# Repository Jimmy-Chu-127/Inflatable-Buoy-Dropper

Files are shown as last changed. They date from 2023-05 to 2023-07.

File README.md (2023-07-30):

# Inflatable Buoy Dropper

### Webpage
https://sites.google.com/ucsd.edu/littlefrog/home?authuser=1

### Demo Video
[](https://youtu.be/II8ibG0zH5Y
"Inflatable Buoy Dropper")

### Objective:
This device is intended to be a drone attachment that can be dropped to drowning victim and inflate upon detecting water.

### Functional Description:
1. Long range dropping control through ESP32 Lora
2. Water sensor to automatically initiate inflation upon hitting water

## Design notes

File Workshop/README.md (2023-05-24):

# Servos and Stepper Motor controls using Arduino
## INDEX
1. Overview
2. PART1: Servos
3. Servos: An introduction
4. Servos: Use cases
5. Servos: Coding and controls
6. Servos: Cool Experiment
8. PART2: Stepper Motors
9. Stepper Motors: An introduction
10. Stepper Motors: Use cases
11. Stepper Motors: Coding and controls
12. Stepper Motors: Cool Experiment

## Servos: An introduction

At its core, a servo motor is a type of motor that can rotate or push parts of a machine with high precision. The key characteristics that set servo motors apart from other types of motors are their control, precision, and feedback.

The unique aspect of servo motors is their use of a "closed-loop" control system. In simple terms, a closed-loop system means that the motor continually receives and responds to feedback about its position or speed, allowing it to make precise adjustments as necessary.

This feedback mechanism typically involves a potentiometer or an encoder that is connected to the motor's output shaft. This device can detect the shaft's current position or speed and send this information back to the motor's control circuit. 

The control circuit then compares the actual position or speed of the shaft with the desired position or speed (as specified by the input signal). If there's a difference, the control circuit will adjust the power to the motor to correct it.

__Factoid__:
The word "servo" comes from the Latin "servus", meaning slave. A servo motor is effectively a slave to its input signals, adjusting its speed, position, or torque based on the instructions it receives.

 Reference: https://howtomechatronics.com/how-it-works/how-servo-motors-work-how-to-control-servos-using-arduino/

### Types of Servos:
 Certainly! There are several types of servo motors, each with unique characteristics and suited to specific applications. Here are some of the most common types:

**1. Standard Servos:** These are the most common types of servo motors. They have a limited rotation angle, typically around 180 degrees. You'll find these in many hobbyist applications like model airplanes or simple robotic arms. These servos have a physical stop built into the gear mechanism to prevent turning beyond these limits.

**2. Continuous Rotation Servos:** Unlike standard servos, continuous rotation servos can rotate 360 degrees continuously in either direction. They are often used for driving wheels on robots because they can turn all the way around. Rather than controlling position, as with standard servos, a command to a continuous rotation servo is interpreted as a speed and direction.

**3. Winch Servos:** These are similar to standard servos, but they have an extended rotation range, typically around 270 degrees. These servos are often used in applications where a larger range of motion is required, such as steering a remote-controlled boat or car.

**4. Linear Servos:** Instead of a rotary actuator, these servos have a linear actuator. This means they move in a straight line rather than rotating. These types of servos are often used in applications where linear motion is required, such as moving a control surface in a straight line.

**5. Large Scale or Giant Servos:** These are high power servos designed for large scale models and other high-stress applications. They provide the same functionality as a standard servo but can deliver much higher torque.

Remember, different servo types require different control signals and power requirements, so always ensure the servo you choose is compatible with your Arduino and the rest of your hardware.

## Servos: Use cases

Servo motors controlled by Arduino find a wide range of applications in various domains due to their precision and control. Here are some key use cases:

**1. Robotics:** In the field of robotics, servos are extensively used. They can be found in robotic arms, legs, or heads to control precise movements. An Arduino can be used to control these servos, allowing you to program complex movements and actions.

**2. Drones and RC Vehicles:** Servo motors are often used in drones and remote-controlled vehicles for steering control, adjusting flight surfaces, or controlling camera gimbal systems. An Arduino can provide the necessary control signals to these servos, making it an ideal choice for hobbyists and professionals alike.

**3. Automation Systems:** In automated systems like home automation or industrial automation, servo motors can be used for a variety of tasks, such as opening or closing valves, adjusting light fixtures, or moving parts in a production line. An Arduino can control these actions based on various sensor inputs.

**4. Interactive Art Installations:** Servo motors controlled by Arduino have become popular in the world of interactive art. They can be used to create moving sculptures, interactive displays, or sound installations, where the motion of the servo motors is controlled by audience interaction.

**5. Animatronics:** In the world of film and entertainment, servos are extensively used in animatronics to create lifelike movements. Arduino can be used to control these servos, making it easier to program and synchronize complex movements.

These examples illustrate just a few of the many possibilities for servo motors controlled by Arduino. With creativity and programming, the applications are virtually endless.

## Servos: Coding and controls

###We focus on regular 180 degree servos first:

The operation of a servo motor is managed by transmitting a sequence of pulses via the signal wire. The control signal should ideally have a frequency of 50Hz, meaning a pulse should be emitted every 20 milliseconds. The angular positioning of the servo is determined by the duration of the pulse. Typically, these servos have the capacity to rotate up to 180 degrees due to their physical constraints on movement.

###Continuous rotation servos:

Continuous rotation servo motors are regulated by a sequence of pulses sent through the signal line. The frequency of the control signal should maintain at 50Hz, which equates to a pulse being produced every 20 milliseconds. Unlike standard servos, the pulse width for a continuous rotation servo does not specify a position, but instead dictates the speed and direction of rotation. These servos, contrary to standard ones, have the ability to rotate without any physical limitations, thereby achieving full 360-degree rotation in either direction.

Arduino code and connections:

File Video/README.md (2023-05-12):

# VIDEO OUTLINE/ IDEAS

## Software:
Davinci Resolve 18

## Ideas
 1. An advert
 2. A video about the problem, solution, roadblock and then the test
    * We should take videos throughout the design process - start early

__IMP:__ 
1. Need to have demo/ deliverable inside of video
2. Need to have voiceovers
3. Find non-copyright music
   
### To Do: 
* Prepare Camera etc for filming in makerspace/ while we are working
* Settle on the format of video - what direction we want
* Decide who is going to edit the video

### Video Outline:
1. Intro - Team name, members - animate this
2. Project Demo - with voiceover - like an advert 
   * Shot of ocean with someone struggling to swim
   * Drone takes off with out attachment
   * Person floats on buoy
4. Cuts of us working on the parts - mashed together - emphasize on one or two bits
5. Outro - with music, credits and links to our project

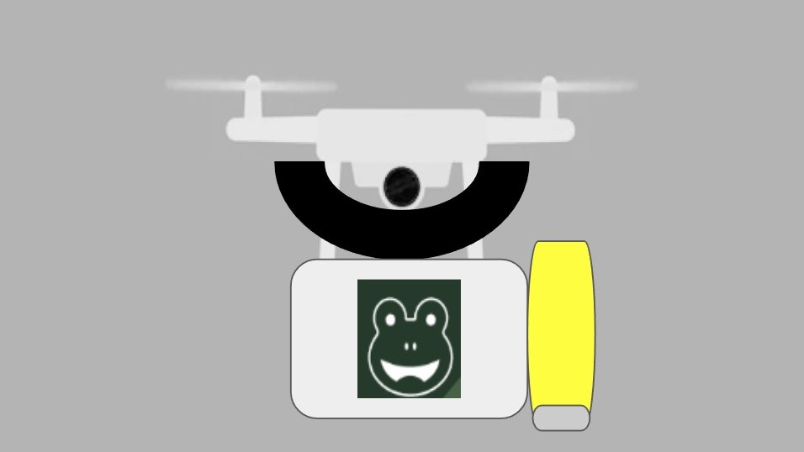
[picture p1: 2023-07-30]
images/Inflatable Buoy Dropper thumbnail.jpg

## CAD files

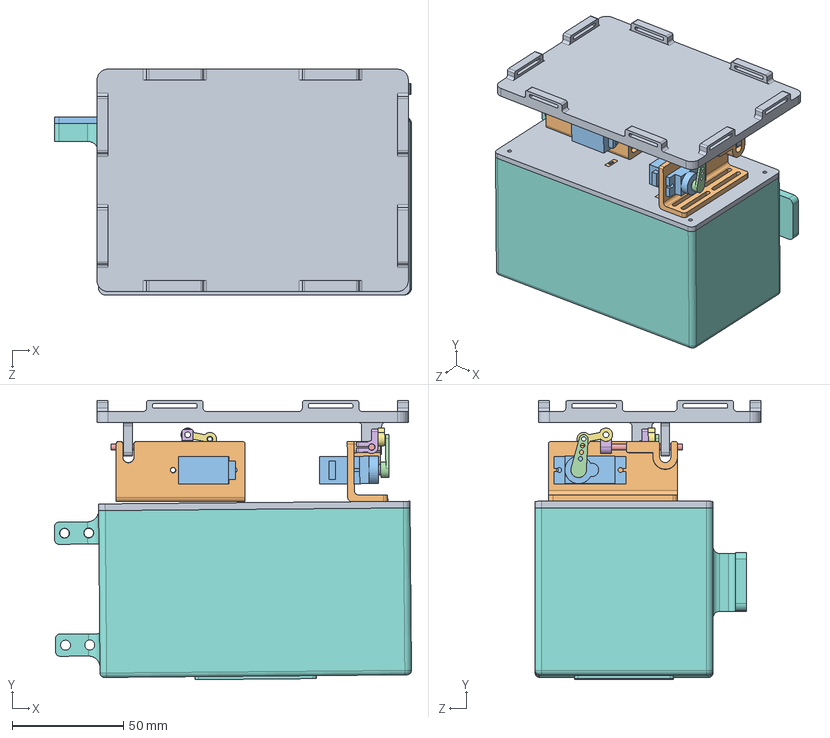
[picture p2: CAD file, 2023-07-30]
Assembly & Parts/Whole mechanism assem.SLDASM
160.4 x 125.5 x 101.5 mm
drone attachment top board
servo attachment x 2
servo x 2
servo arm x 2
servo rod x 2
servo connector 2 x 2
servo connector 3 x 2
PCB Enclosure V3
PCB Enclosure V3 cap
PCB Enclosure water insert x 4

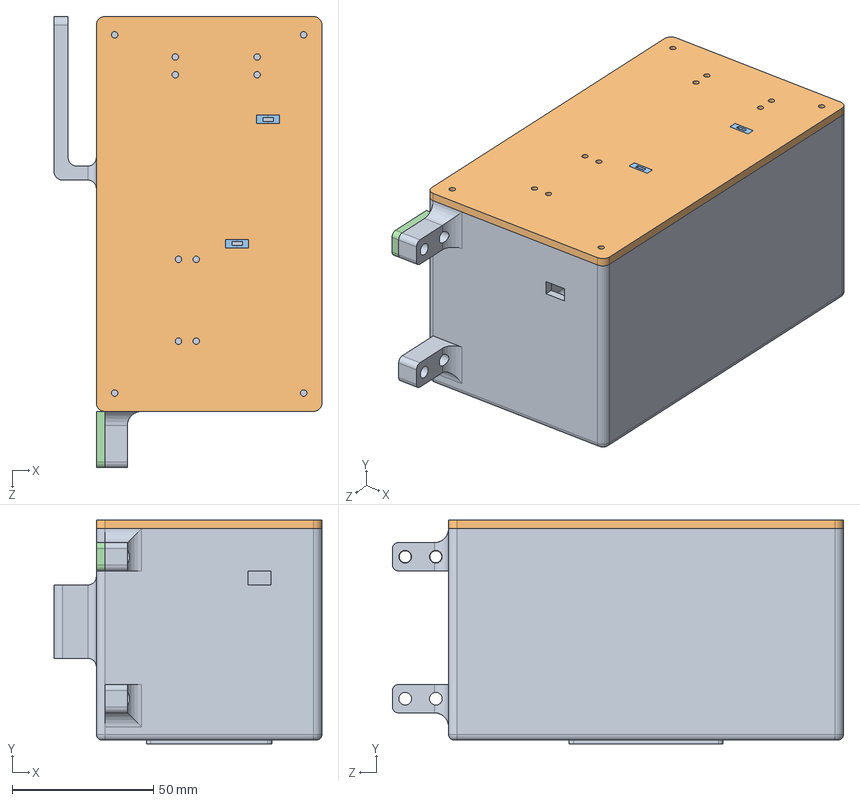
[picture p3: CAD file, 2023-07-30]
Assembly & Parts/PCB Enclosure Assem.SLDASM
95.0 x 79.3 x 159.9 mm
PCB Enclosure V3
PCB Enclosure V3 cap
PCB Enclosure water insert x 4

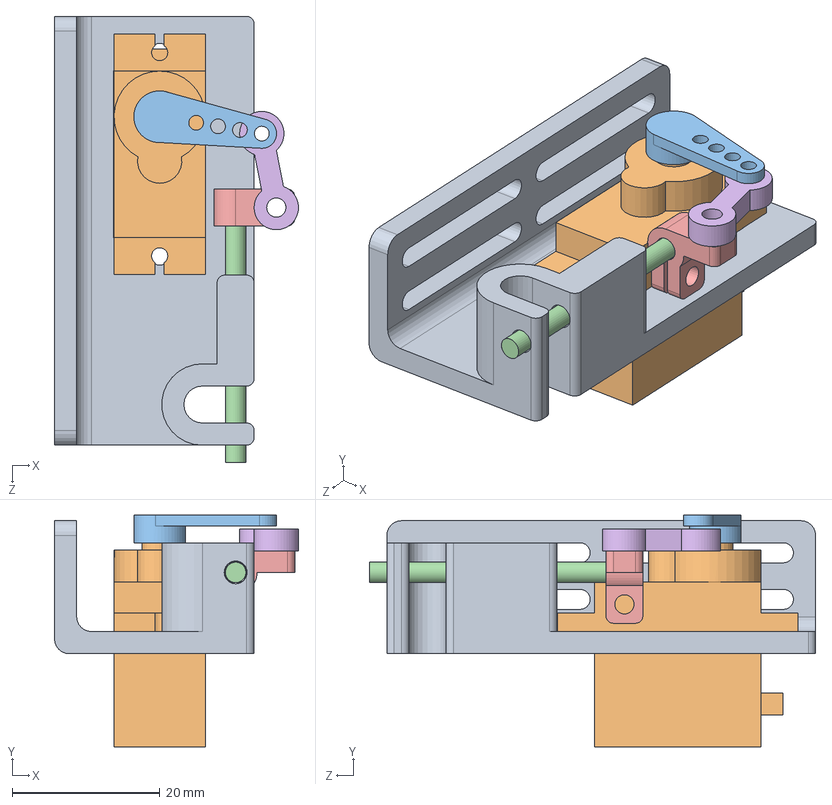
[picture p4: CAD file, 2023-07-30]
Assembly & Parts/servo drop mechanism.SLDASM
33.0 x 31.4 x 60.4 mm
servo attachment
servo
servo arm
servo rod
servo connector 2
servo connector 3

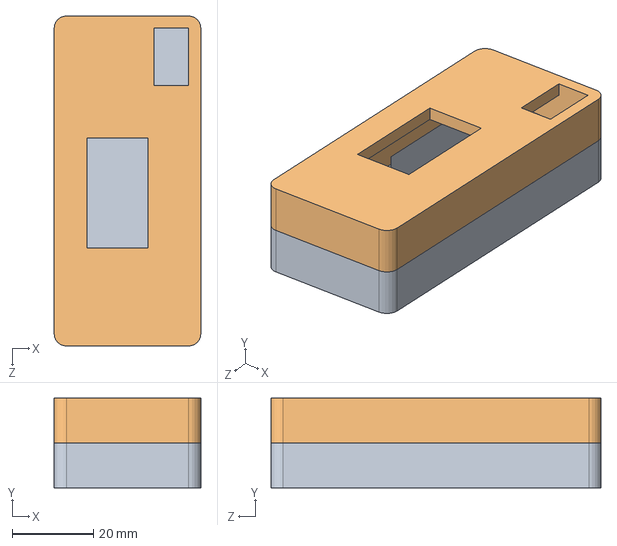
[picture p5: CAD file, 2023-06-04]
Assembly & Parts/Controller Assem.SLDASM
36.0 x 22.0 x 81.0 mm
Controller Enclosure bottom
Controller Enclosure top

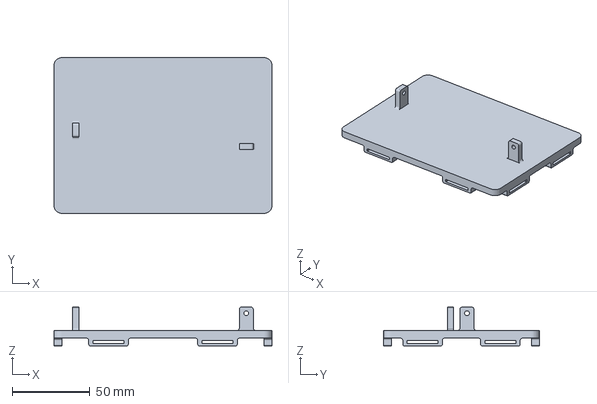
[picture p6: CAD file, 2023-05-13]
3D printing STL files/5.12/drone attachment top board.3mf
140.0 x 100.0 x 25.0 mm

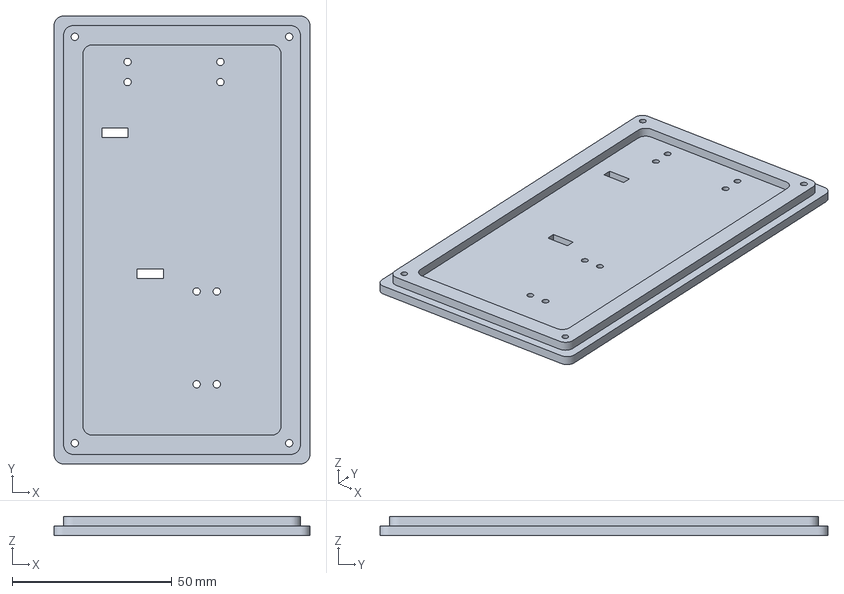
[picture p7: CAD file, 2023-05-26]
3D printing STL files/5.24/3mf/PCB Enclosure V3 cap.3mf
80.0 x 140.0 x 6.00 mm

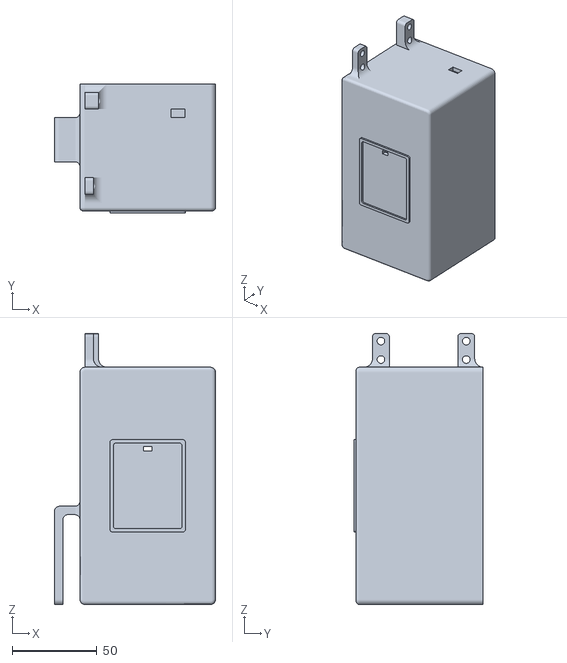
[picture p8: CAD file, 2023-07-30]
3D printing STL files/PCB Enclosure V3.STL
95.0 x 76.4 x 159.9

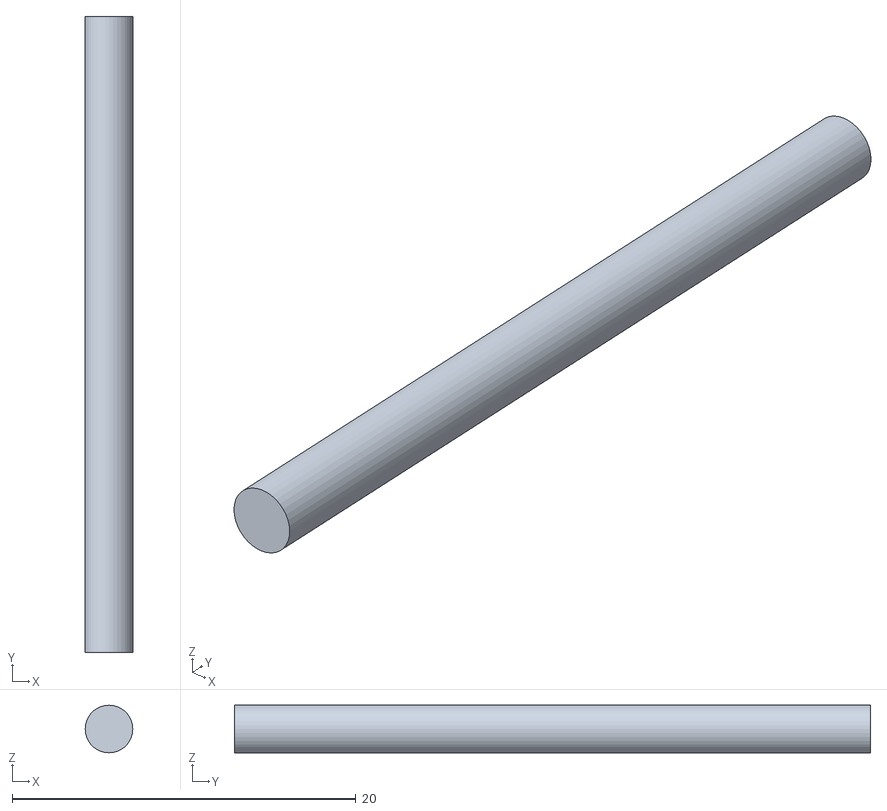
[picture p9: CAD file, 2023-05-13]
3D printing STL files/5.12/servo rod.STL
2.77 x 37.0 x 2.77

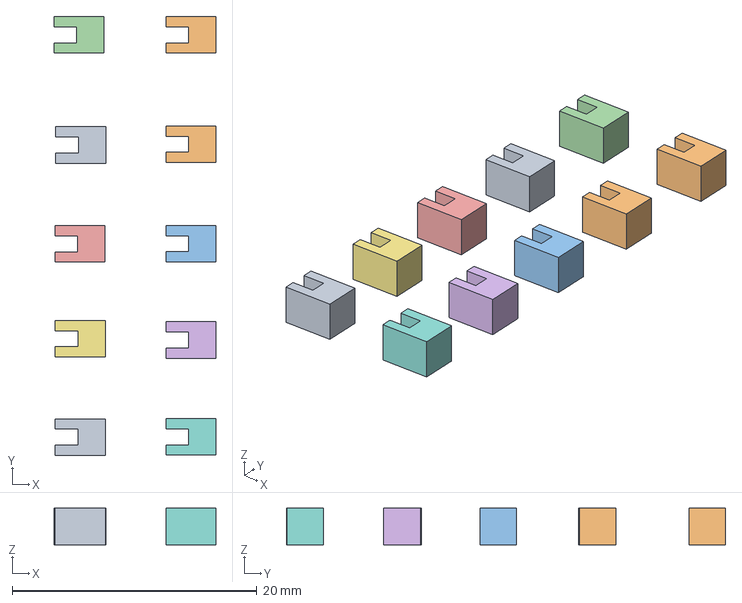
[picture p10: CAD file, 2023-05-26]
3D printing STL files/5.24/3mf/PCB Enclosure water insert.3mf
13.2 x 35.9 x 3.00 mm
PCB Enclosure water insert.STL x 10

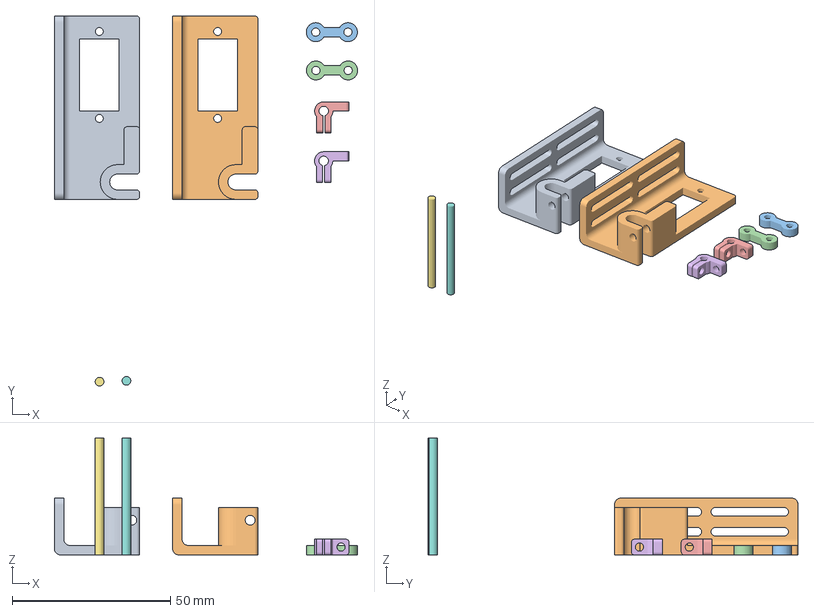
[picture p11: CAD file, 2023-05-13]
3D printing STL files/5.12/servo attachment etc.3mf
95.9 x 117.0 x 37.0 mm
servo attachment.STL x 2
servo connector 3.STL x 2
servo connector 2.STL x 2
servo rod.STL x 2

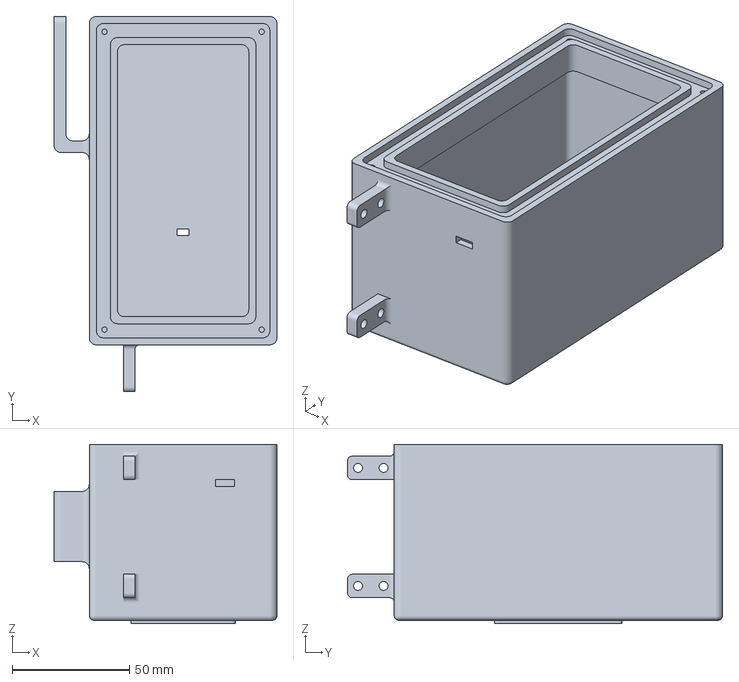
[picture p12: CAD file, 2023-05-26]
3D printing STL files/5.24/3mf/PCB Enclosure V3.3mf
95.0 x 159.9 x 76.4 mm

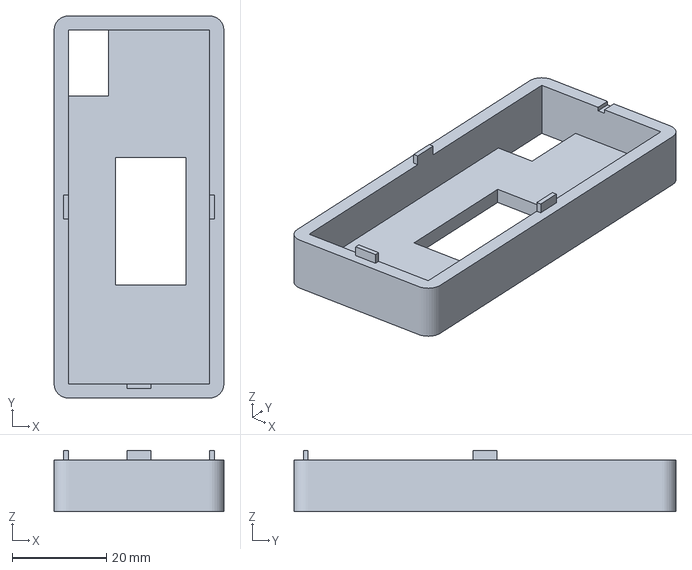
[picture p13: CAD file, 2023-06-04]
3D printing STL files/Controller Enclosure top.3mf
36.0 x 81.0 x 13.0 mm

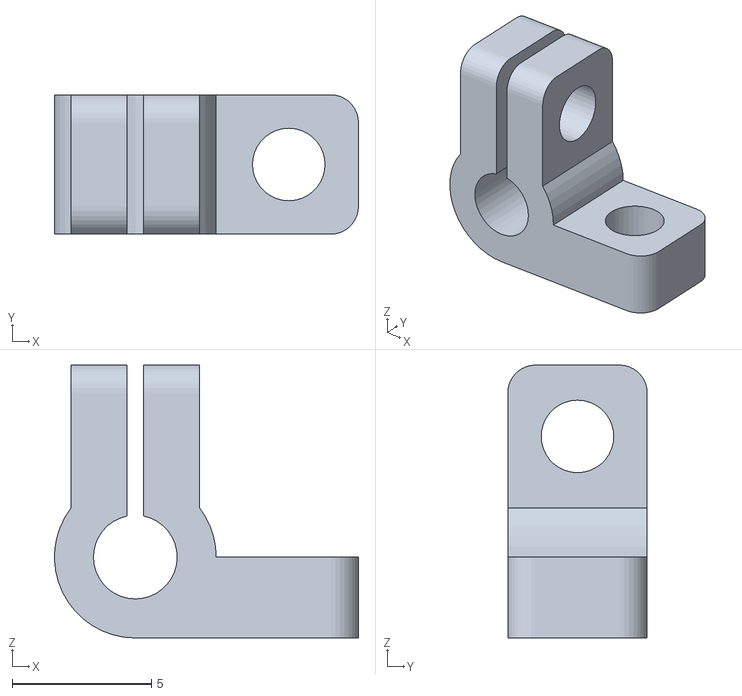
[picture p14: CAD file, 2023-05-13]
3D printing STL files/5.12/servo connector 2.STL
10.9 x 5.00 x 9.78

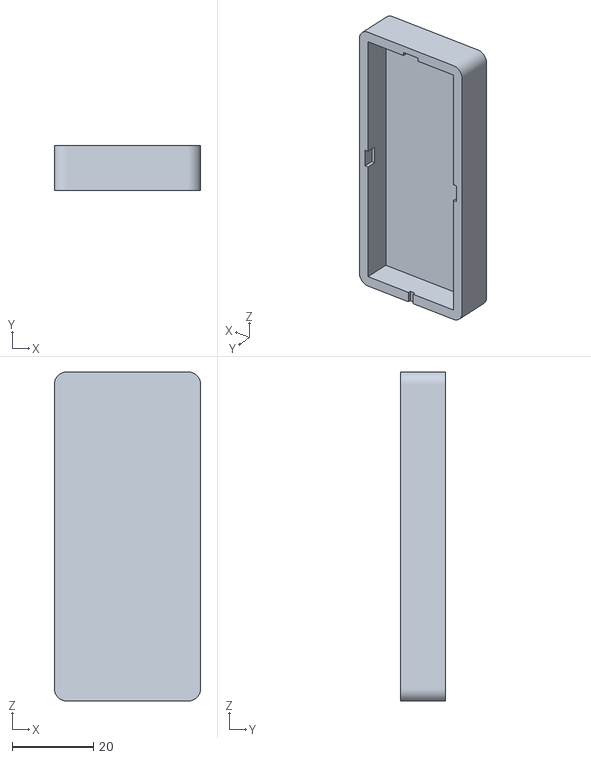
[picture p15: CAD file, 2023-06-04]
3D printing STL files/Controller Enclosure bottom.STL
36.0 x 11.0 x 81.0

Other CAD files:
Assembly & Parts/PCB Enclosure V3 cap.SLDPRT
3D printing STL files/PCB Enclosure V4.3mf
Assembly & Parts/PCB Enclosure V3.SLDPRT
3D printing STL files/5.12/servo connector 3.STL
3D printing STL files/5.12/drone attachment top board.STL
3D printing STL files/5.12/servo attachment.STL
3D printing STL files/5.24/STL/PCB Enclosure V3 cap.STL
3D printing STL files/5.24/STL/PCB Enclosure V3.STL
3D printing STL files/5.24/STL/PCB Enclosure water insert.STL
3D printing STL files/Controller Enclosure top.STL
3D printing STL files/servo height pad.STL
Assembly & Parts/Controller Enclosure bottom.SLDPRT
Assembly & Parts/Controller Enclosure top.SLDPRT
Assembly & Parts/PCB Enclosure V2.SLDPRT
Assembly & Parts/PCB Enclosure water insert.SLDPRT
Assembly & Parts/PCB Enclosure.sldprt
Assembly & Parts/bottom attachment board.SLDPRT
Assembly & Parts/buoy holder.SLDPRT
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

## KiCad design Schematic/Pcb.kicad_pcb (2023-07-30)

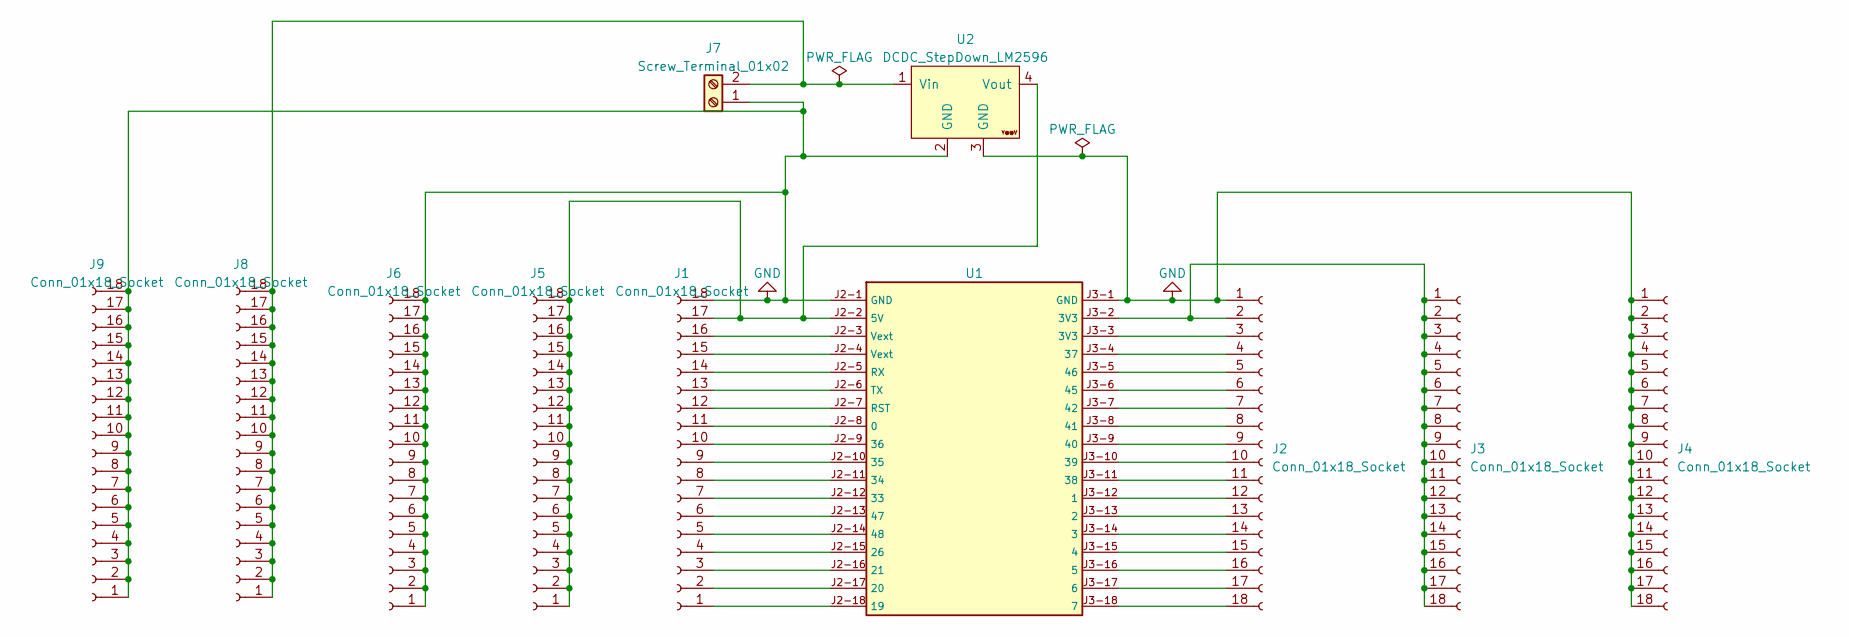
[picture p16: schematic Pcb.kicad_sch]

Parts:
J1, J2, J3, J4, J5, J6, J8, J9: Conn_01x18_Socket; PinSocket_1x18_P2.54mm_Vertical
J7: Screw_Terminal_01x02; TerminalBlock_Altech_AK300-2_P5.00mm
U1: esp32Lora_foot_Print
U2: DCDC_StepDown_LM2596

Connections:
GND: J1.18, J2.1, J4.1, J4.2, J4.3, J4.4, J4.5, J4.6, J4.7, J4.8, J4.9, J4.10, J4.11, J4.12, J4.13, J4.14, J4.15, J4.16, J4.17, J4.18, J6.1, J6.2, J6.3, J6.4, J6.5, J6.6, J6.7, J6.8, J6.9, J6.10, J6.11, J6.12, J6.13, J6.14, J6.15, J6.16, J6.17, J6.18, J7.1, J9.1, J9.2, J9.3, J9.4, J9.5, J9.6, J9.7, J9.8, J9.9, J9.10, J9.11, J9.12, J9.13, J9.14, J9.15, J9.16, J9.17, J9.18, U1.J2-1 (GND), U1.J3-1 (GND), U2.2 (GND), U2.3 (GND)
unnamed: J1.1, U1.J2-18 (19)
unnamed: J1.2, U1.J2-17 (20)
unnamed: J1.3, U1.J2-16 (21)
unnamed: J1.4, U1.J2-15 (26)
unnamed: J1.5, U1.J2-14 (48)
unnamed: J1.6, U1.J2-13 (47)
unnamed: J1.7, U1.J2-12 (33)
unnamed: J1.8, U1.J2-11 (34)
unnamed: J1.9, U1.J2-10 (35)
unnamed: J1.10, U1.J2-9 (36)
unnamed: J1.11, U1.J2-8 (0)
unnamed: J1.12, U1.J2-7 (RST)
unnamed: J1.13, U1.J2-6 (TX)
unnamed: J1.14, U1.J2-5 (RX)
unnamed: J1.15, U1.J2-4 (Vext)
unnamed: J1.16, U1.J2-3 (Vext)
unnamed: J1.17, J5.1, J5.2, J5.3, J5.4, J5.5, J5.6, J5.7, J5.8, J5.9, J5.10, J5.11, J5.12, J5.13, J5.14, J5.15, J5.16, J5.17, J5.18, U1.J2-2 (5V), U2.4 (Vout)
unnamed: J2.2, J3.1, J3.2, J3.3, J3.4, J3.5, J3.6, J3.7, J3.8, J3.9, J3.10, J3.11, J3.12, J3.13, J3.14, J3.15, J3.16, J3.17, J3.18, U1.J3-2 (3V3)
unnamed: J2.3, U1.J3-3 (3V3)
unnamed: J2.4, U1.J3-4 (37)
unnamed: J2.5, U1.J3-5 (46)
unnamed: J2.6, U1.J3-6 (45)
unnamed: J2.7, U1.J3-7 (42)
unnamed: J2.8, U1.J3-8 (41)
unnamed: J2.9, U1.J3-9 (40)
unnamed: J2.10, U1.J3-10 (39)
unnamed: J2.11, U1.J3-11 (38)
unnamed: J2.12, U1.J3-12 (1)
unnamed: J2.13, U1.J3-13 (2)
unnamed: J2.14, U1.J3-14 (3)
unnamed: J2.15, U1.J3-15 (4)
unnamed: J2.16, U1.J3-16 (5)
unnamed: J2.17, U1.J3-17 (6)
unnamed: J2.18, U1.J3-18 (7)
unnamed: J7.2, J8.1, J8.2, J8.3, J8.4, J8.5, J8.6, J8.7, J8.8, J8.9, J8.10, J8.11, J8.12, J8.13, J8.14, J8.15, J8.16, J8.17, J8.18, U2.1 (Vin)

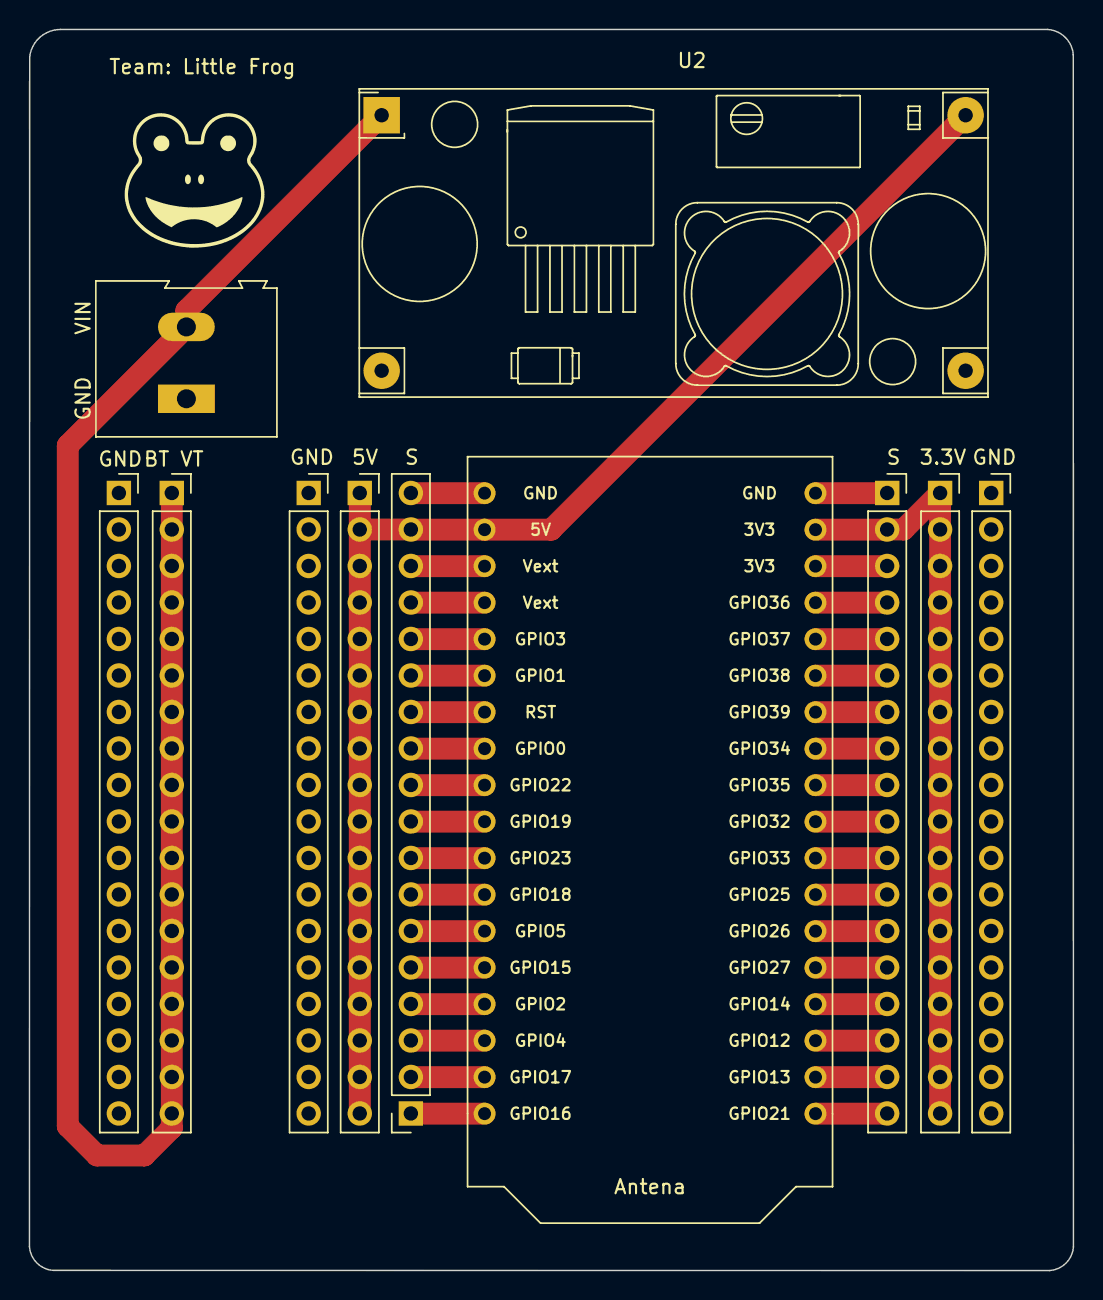
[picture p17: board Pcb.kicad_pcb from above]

Board: 2 copper layers, 72.7 x 86.4 mm, 11 parts (0 on the bottom side), 36 nets.

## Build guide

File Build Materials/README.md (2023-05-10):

# Possible Servos

4x non- waterproof 360 degrees: https://www.amazon.com/DEVMO-360%C2%B0High-Torque-Helicopter-Airplane/dp/B07X3S6FM2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

Waterproof 360 degrees: 70$
https://www.amazon.com/Reefs-RC-REEFS83-Coreless-Synthetic/dp/B08WPJC16K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

Waterproof 270 degrees: https://www.amazon.com/Youleke-Torque-Digital-Servo%EF%BC%8CWaterproof-Horn%EF%BC%88270%C2%B0%EF%BC%89/dp/B08739MGPL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

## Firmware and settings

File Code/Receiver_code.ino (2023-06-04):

#include "heltec.h" 
#include "images.h"
#include <ESP32Servo.h>

#define TURN_TIME 175
#define BAND    915E6  //you can set band here directly,e.g. 868E6,915E6
String rssi = "RSSI --";
String packSize = "--";
String packet ;

Servo servo1;  // create servo object to control a servo
Servo servo2;
Servo servo3;
// twelve servo objects can be created on most boards
int pos = 0;    // variable to store the servo position
bool val = true;
bool val2 = true;

int servo1Pin = 13;
int servo2Pin = 12;
int servo3Pin = 2;
int i = 180;


void logo(){
  Heltec.display->clear();
  Heltec.display->drawXbm(0,5,logo_width,logo_height,logo_bits);
  Heltec.display->display();
}

void LoRaData(){
  Heltec.display->clear();
  Heltec.display->setTextAlignment(TEXT_ALIGN_LEFT);
  Heltec.display->setFont(ArialMT_Plain_10);
  Heltec.display->drawString(0 , 15 , "Received "+ packSize + " bytes");
  Heltec.display->drawStringMaxWidth(0 , 26 , 128, packet);
  Heltec.display->drawString(0, 0, rssi);  
  Heltec.display->display();
}

void cbk(int packetSize) {
  packet ="";
  packSize = String(packetSize,DEC);
  for (int i = 0; i < packetSize; i++) { packet += (char) LoRa.read(); }
  rssi = "RSSI " + String(LoRa.packetRssi(), DEC) ;
  LoRaData();
}

void setup() { 
   //WIFI Kit series V1 not support Vext control
  Heltec.begin(true /*DisplayEnable Enable*/, true /*Heltec.Heltec.Heltec.LoRa Disable*/, true /*Serial Enable*/, true /*PABOOST Enable*/, BAND /*long BAND*/);
 
  Heltec.display->init();
  Heltec.display->flipScreenVertically();  
  Heltec.display->setFont(ArialMT_Plain_10);
  logo();
  delay(1500);
  Heltec.display->clear();
  
  Heltec.display->drawString(0, 0, "Heltec.LoRa Initial success!");
  Heltec.display->drawString(0, 10, "Wait for incoming data...");
  Heltec.display->display();
  delay(1000);
  //LoRa.onReceive(cbk);
  LoRa.receive();
  ESP32PWM::allocateTimer(0);
	ESP32PWM::allocateTimer(1);
	ESP32PWM::allocateTimer(2);
	ESP32PWM::allocateTimer(3);
	servo1.setPeriodHertz(50);    // standard 50 hz servo
	servo1.attach(servo1Pin, 500, 2400); // attaches the servo on pin 18 to the servo object
  servo2.setPeriodHertz(50);    // standard 50 hz servo
	servo2.attach(servo2Pin, 500, 2400); // attaches the servo on pin 18 to the servo object
  servo3.setPeriodHertz(50);    // standard 50 hz servo
	servo3.attach(servo3Pin, 500, 2500);
  servo1.write(70);
  servo3.write(0);
  Serial.begin(9600);
}

void loop() {
  int packetSize = LoRa.parsePacket();
 if (packetSize) 
 { 
   if (val2){
    servo1.write(130);
    servo2.write(120);
    delay(1000);
    // servo1.detach();
    // servo2.detach();
    val2 = false;
   }
    int sensorReading = analogRead(36);
    Serial.println(val);
    if (sensorReading < 3000 && (val==true))
    {
		servo3.write(180);    // tell servo to go to position in variable 'pos'
    delay(1000);
    val = false;
	}
  
    }
   }
    
	

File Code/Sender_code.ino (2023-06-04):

#include "heltec.h"
#include "images.h"

#define BAND    915E6  //you can set band here directly,e.g. 868E6,915E6
int btn1 = 36;
//const int ledPin = 36;    // the number of the LED pin

// variables will change:
int buttonState = 0;  // variable for reading the pushbutton status
unsigned int counter = 0;
String rssi = "RSSI --";
String packSize = "--";
String packet ;

void logo()
{
  Heltec.display->clear();
  Heltec.display->drawXbm(0,5,logo_width,logo_height,logo_bits);
  Heltec.display->display();
}

void setup()
{
   //WIFI Kit series V1 not support Vext control
  Heltec.begin(true /*DisplayEnable Enable*/, true /*Heltec.Heltec.Heltec.LoRa Disable*/, true /*Serial Enable*/, true /*PABOOST Enable*/, BAND /*long BAND*/);
 
  Heltec.display->init();
  Heltec.display->flipScreenVertically();  
  Heltec.display->setFont(ArialMT_Plain_10);
  logo();
  delay(1500);
  Heltec.display->clear();
  
  Heltec.display->drawString(0, 0, "Heltec.LoRa Initial success!");
  Heltec.display->display();
  delay(1000);
  pinMode(btn1, INPUT);
  // initialize the pushbutton pin as an input:
  
}

void loop()
{
  
  if (digitalRead(btn1) == HIGH) //Caso o botão 1 foi pressionado {
    // turn LED on:
  {
  Heltec.display->clear();
  Heltec.display->setTextAlignment(TEXT_ALIGN_LEFT);
  Heltec.display->setFont(ArialMT_Plain_10);
  
  Heltec.display->drawString(0, 0, "Sending packet: ");
  Heltec.display->drawString(90, 0, String(counter));
  Heltec.display->display();

  // send packet
  LoRa.beginPacket();
  LoRa.setTxPower(14,RF_PACONFIG_PASELECT_PABOOST);
  LoRa.print("hello ");
  LoRa.print(counter);
  LoRa.endPacket();

  counter++;
  digitalWrite(LED, HIGH);   // turn the LED on (HIGH is the voltage level)
  delay(1000);                       // wait for a second
  digitalWrite(LED, LOW);    // turn the LED off by making the voltage LOW
  delay(1000);   
  } 
}



 

  

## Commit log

2023-05-04 dropping mechanism update
    [drone attachment top board.SLDPRT, servo arm.SLDPRT, servo attachment.SLDPRT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]
2023-05-04 dimension adjustments
    [Whole mechanism assem.SLDASM, drone attachment top board.SLDPRT, servo connector 2.SLDPRT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]
2023-05-11 whole assem update
    [Whole mechanism assem.SLDASM, servo drop mechanism.SLDASM]
2023-05-13 3D printing slicing
    [Whole mechanism assem.SLDASM, drone attachment top board.3mf, drone attachment top board.SLDPRT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]
2023-05-13 G code clearance modification
    [Whole mechanism assem.SLDASM, drone attachment top board.3mf, drone attachment top board.SLDPRT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]
2023-05-16 Update servo drop mechanism.SLDASM
    [servo drop mechanism.SLDASM]
2023-05-21 whole mechanism update
    [PCB Enclosure V2.SLDPRT, PCB Enclosure.sldprt, Whole mechanism assem.SLDASM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]
2023-05-24 PCB enclosure update
    [PCB Enclosure V2.SLDPRT, PCB Enclosure V3.SLDPRT, Whole mechanism assem.SLDASM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]
2023-05-25 New PCB enclosure design, whole assembly inclusion
    [PCB Enclosure Assem.SLDASM, PCB Enclosure V3 cap.SLDPRT, PCB Enclosure V3.SLDPRT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]
2023-05-25 3D printing files update
    [PCB Enclosure V3 cap.STL, PCB Enclosure V3.STL, drone attachment top board.3mf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]
2023-05-25 PCB enclosure and whole assembly update
    [PCB Enclosure Assem.SLDASM, PCB Enclosure V3.SLDPRT, Whole mechanism assem.SLDASM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]
2023-05-26 small update
    [PCB Enclosure Assem.SLDASM, Whole mechanism assem.SLDASM]
2023-05-26 PCB enclosure 3D printing file update
    [PCB Enclosure V3 cap.3mf, PCB Enclosure V3.3mf, PCB Enclosure V3.STL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]
2023-07-30 Organizing file structure
    [Controller Assem.SLDASM, Controller Enclosure bottom.SLDPRT, Controller Enclosure top.SLDPRT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]
